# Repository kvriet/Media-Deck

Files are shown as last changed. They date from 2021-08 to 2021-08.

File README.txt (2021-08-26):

// README for the Media Deck by C.M. van Riet - 6 August 2021

Components:
- Arduino Pro Micro (with or without headers)
- 6x Cherry MX (-like) switches
- 6x Cherry MX compatible keycaps
- 6x diode (1N4148 SOD-323)
- 6x 100nF cap (0805) OPTIONAL
- 6x reverse-mounted LED (SK6812 3228)
- 1x slider potentiometer 35mm 3 foot
- 2x female or male header
- 4x mini screw (M1.7x5)

Printing and assembly:
Print the base without supports (0.2 or 0.3 mm layer height).
Print the top with supports (upside down) and support on build plate only (0.2mm layer height).

For a deck with Arduino hidden: print 'top closed' and solder Arduino onto PCB with male headers. Cut off excess pin length.

For a deck with Arduino visible: print 'top open' and solder female headers onto pcb and male headers onto Arduino. 

Solder PCB as indicated by silkscreen.

Join 3 parts (top, PCB, base) and screw shut.

Software:
Choose your own key codes for the media deck and upload sketch to Arduino Pro Micro (choosing Arduino Leonardo in Arduino application also works).

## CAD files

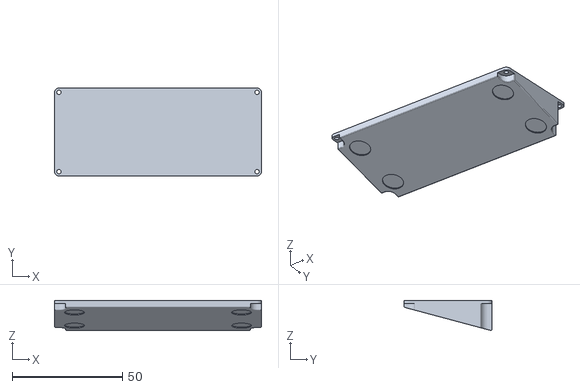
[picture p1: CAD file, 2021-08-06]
STLs/base v2.stl
94.0 x 40.0 x 13.6

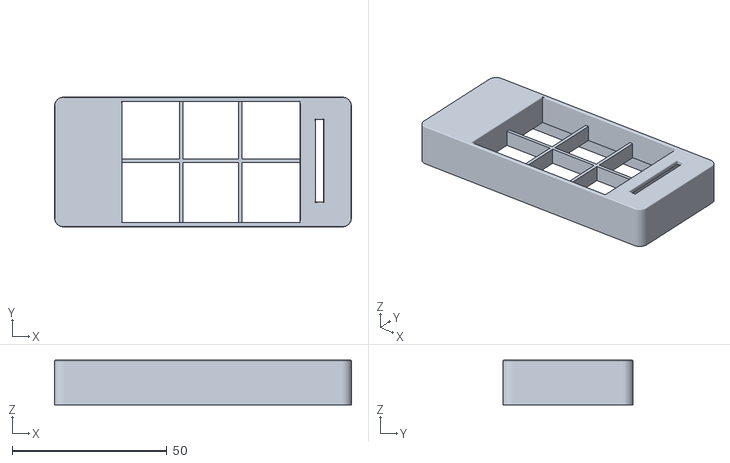
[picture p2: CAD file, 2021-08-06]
STLs/top closed v3.stl
96.0 x 42.0 x 14.5

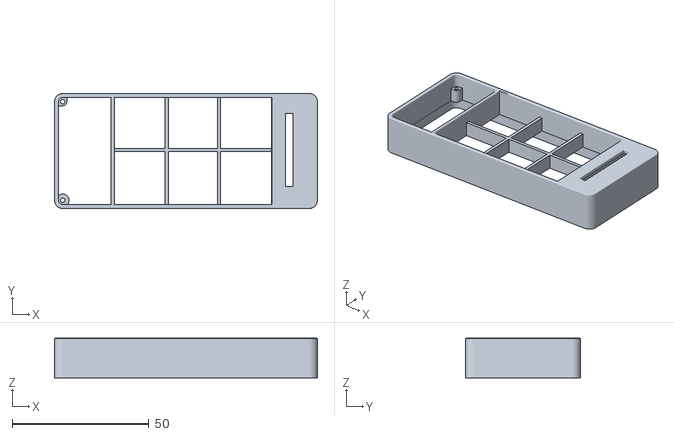
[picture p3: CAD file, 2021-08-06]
STLs/top open v2.stl
96.0 x 42.0 x 14.5

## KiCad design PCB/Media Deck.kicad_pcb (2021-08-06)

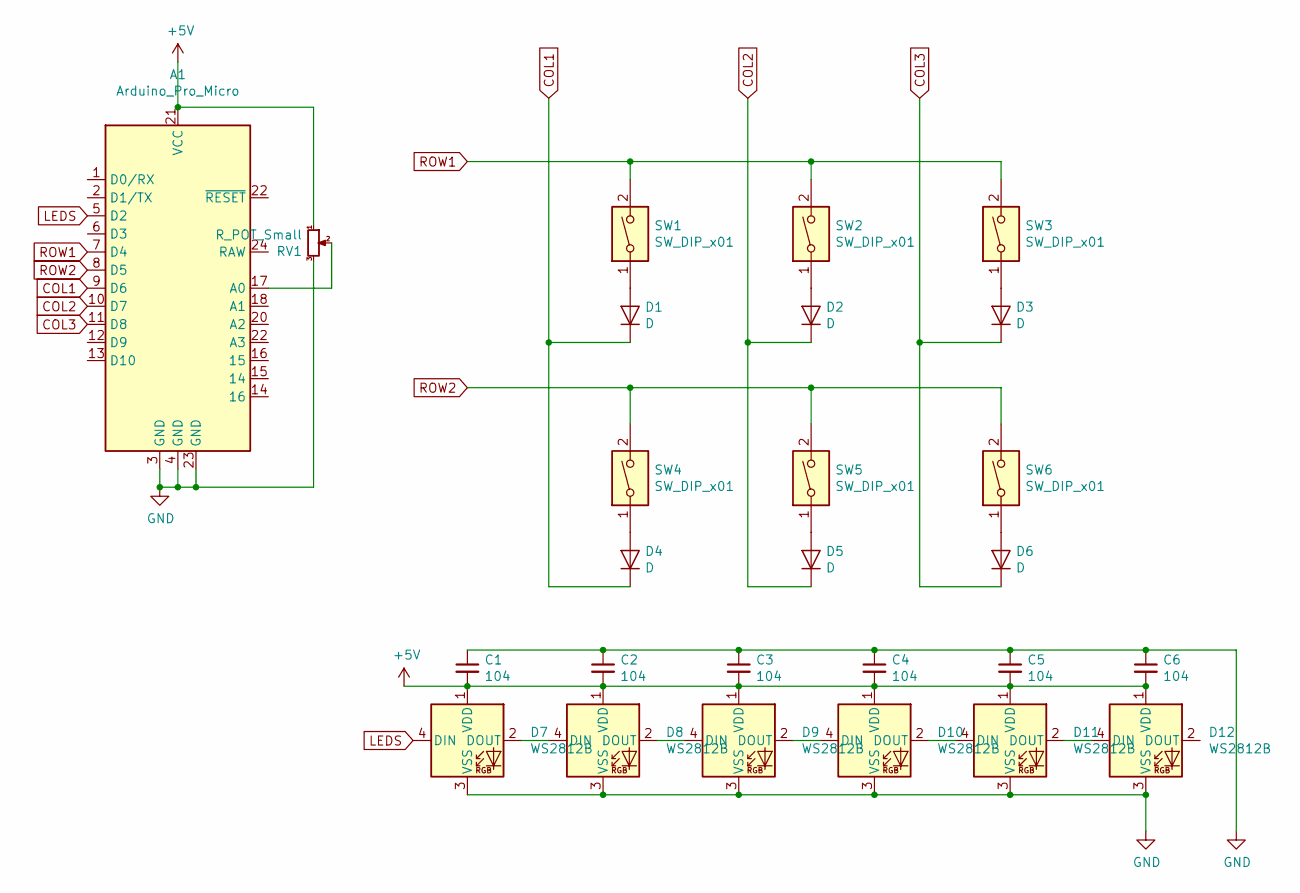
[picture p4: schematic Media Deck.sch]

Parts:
A1: Arduino_Pro_Micro
C1, C2, C3, C4, C5, C6: 104; C_0805_2012Metric
D1, D2, D3, D4, D5, D6: D; D_0805_2012Metric_Pad1.15x1.40mm_HandSolder
D7, D8, D9, D10, D11, D12: WS2812B; LED_SK6812MINI_REVERSE
RV1: R_POT_Small; Pot_Slider_35mm
SW1, SW2, SW3, SW4, SW5, SW6: SW_DIP_x01; SW_Cherry_MX_1.00u_Plate

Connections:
+5V: A1.21 (VCC), C1.2, C2.2, C3.2, C4.2, C5.2, C6.2, D7.1 (VDD), D8.1 (VDD), D9.1 (VDD), D10.1 (VDD), D11.1 (VDD), D12.1 (VDD), RV1.1
COL1: A1.9 (D6), D1.1 (K), D4.1 (K)
COL2: A1.10 (D7), D2.1 (K), D5.1 (K)
COL3: A1.11 (D8), D3.1 (K), D6.1 (K)
GND: A1.3 (GND), A1.4 (GND), A1.23 (GND), C1.1, C2.1, C3.1, C4.1, C5.1, C6.1, D7.3 (VSS), D8.3 (VSS), D9.3 (VSS), D10.3 (VSS), D11.3 (VSS), D12.3 (VSS), RV1.3
LEDS: A1.5 (D2), D7.4 (DIN)
unnamed: A1.17 (A0), RV1.2
unnamed: D1.2 (A), SW1.1
unnamed: D2.2 (A), SW2.1
unnamed: D3.2 (A), SW3.1
unnamed: D4.2 (A), SW4.1
unnamed: D5.2 (A), SW5.1
unnamed: D6.2 (A), SW6.1
unnamed: D7.2 (DOUT), D8.4 (DIN)
unnamed: D8.2 (DOUT), D9.4 (DIN)
unnamed: D10.2 (DOUT), D11.4 (DIN)
unnamed: D9.2 (DOUT), D10.4 (DIN)
unnamed: D11.2 (DOUT), D12.4 (DIN)
ROW1: A1.7 (D4), SW1.2, SW2.2, SW3.2
ROW2: A1.8 (D5), SW4.2, SW5.2, SW6.2

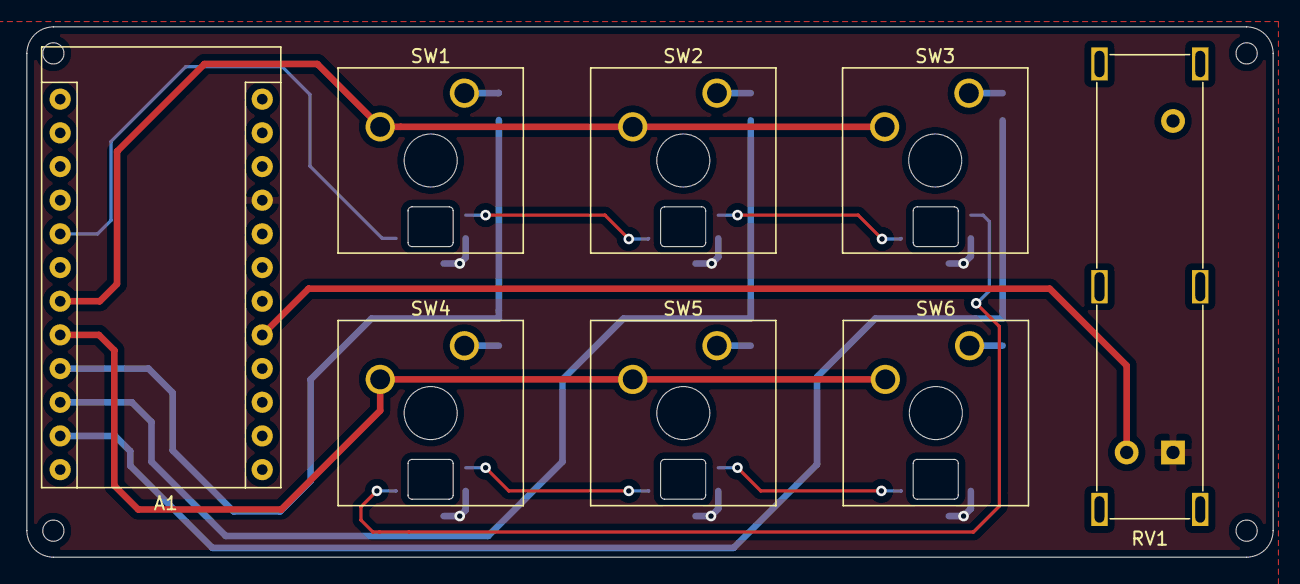
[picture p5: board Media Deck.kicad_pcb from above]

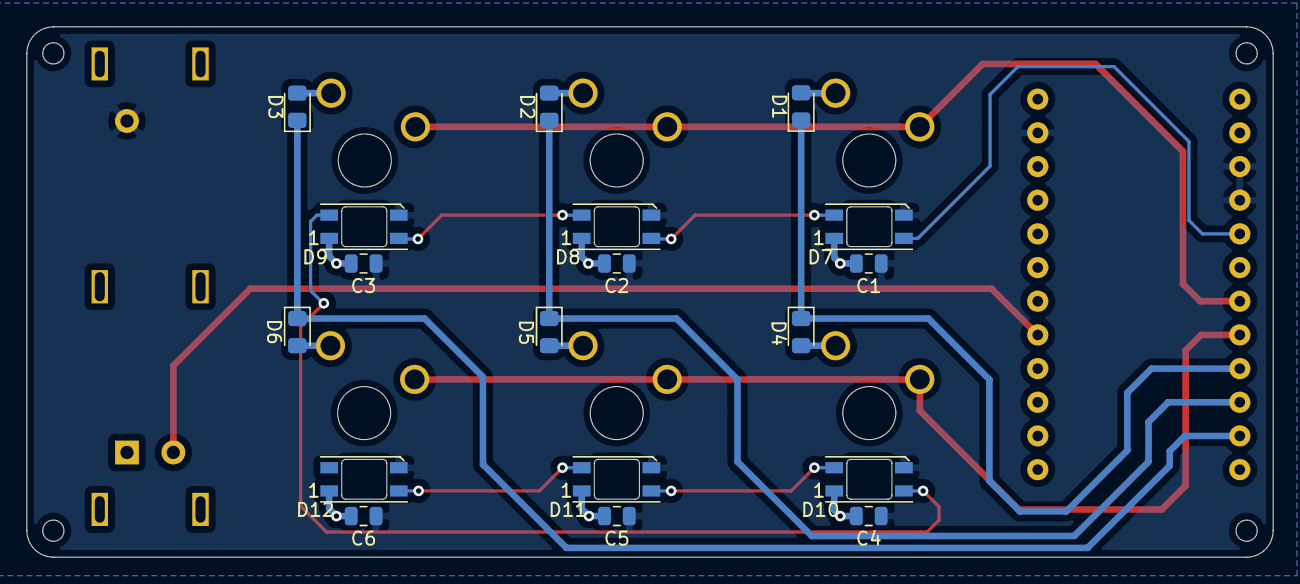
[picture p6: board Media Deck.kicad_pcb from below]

Board: 2 copper layers, 94.0 x 40.0 mm, 26 parts (18 on the bottom side), 20 nets.

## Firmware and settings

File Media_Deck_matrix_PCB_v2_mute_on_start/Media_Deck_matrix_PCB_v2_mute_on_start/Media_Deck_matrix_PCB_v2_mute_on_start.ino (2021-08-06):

// Media Deck - Katrien van Riet - July 2021 - version 3
// Volume code adapted from: https://create.arduino.cc/projecthub/Arnov_Sharma_makes/hid-volume-knob-with-pro-micro-db0bf8

#include <HID-Project.h>
#include <HID-Settings.h>
#include <Keypad.h>
#include <FastLED.h>

#define LED_PIN     2
#define NUM_LEDS    6
#define BRIGHTNESS  50
#define LED_TYPE    WS2812B
#define COLOR_ORDER GRB
CRGB leds[NUM_LEDS];

#define UPDATES_PER_SECOND 100

// PINS
const byte ROWS = 2;
const byte COLS = 3;
char keys[ROWS][COLS] = {
  {'1', '2', '3'},
  {'4', '5', '6'},
};
byte rowPins[ROWS]              = {4, 5}; 
byte colPins[COLS]              = {6, 7, 8}; 
const int volume_pin            = A3;
const int ledPin                = 2;
Keypad keypad = Keypad( makeKeymap(keys), rowPins, colPins, ROWS, COLS );

//VARIABLES
bool isMicOn                    = true;
int volumeVal                   = 0;
int prevVolumeVal               = 0;
int volumeVal2                  = 0;
const long debounce_delay       = 5;

void setup() {
  pinMode(ledPin, OUTPUT);
  pinMode(LED_BUILTIN_TX, INPUT);           // Disables TX LED so it doesn't light up when a button is pushed.
  pinMode(LED_BUILTIN_RX, INPUT);           // Disables TX LED so it doesn't light up when a button is pushed.
  FastLED.addLeds<LED_TYPE, LED_PIN, COLOR_ORDER>(leds, NUM_LEDS).setCorrection( TypicalLEDStrip );
  FastLED.setBrightness(  BRIGHTNESS );
  for (int i = 0; i < NUM_LEDS; i++) {
    leds[i] = CRGB(0, 0, 0);
  }
  Consumer.begin();                         // Initialize computer connection
  delay(1000);                              // Wait for computer to connect
  for (int a = 0; a < 52; a++) {
    Consumer.write(MEDIA_VOLUME_DOWN);      // Set the volume to 0
    delay(2);
  }
  Keyboard.begin();
  //  Serial.begin(115200);
}

void loop() {
  checkButtons();
  checkVolume();
  checkLEDs();
}

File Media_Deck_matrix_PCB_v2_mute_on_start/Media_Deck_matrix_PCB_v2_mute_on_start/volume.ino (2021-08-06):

void checkVolume() {
  volumeVal = analogRead(volume_pin);           // Read potentiometer value
  volumeVal = map(volumeVal, 0, 1023, 101, 0);  // Map it to 102 steps
  if (abs(volumeVal - prevVolumeVal) > 1) {     // Check if potentiometer value has changed
    prevVolumeVal = volumeVal;
    volumeVal /= 2;                             // Divide it by 2 to get 51 steps
    while (volumeVal2 < volumeVal) {
      Consumer.write(MEDIA_VOLUME_UP);          // Turn volume up to appropiate level
      volumeVal2++;
      delay(2);
    }
    while (volumeVal2 > volumeVal) {
      Consumer.write(MEDIA_VOLUME_DOWN);        // Turn volume down to appropiate level
      volumeVal2--;
      delay(2);
    }
    delay(301);
  }
}
